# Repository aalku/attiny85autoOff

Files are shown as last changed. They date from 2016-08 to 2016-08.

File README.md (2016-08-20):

# attiny85autoOff
Circuit/Software that allow Attiny 85 to be powered on with a button and later power off itself.

With this circuit your microcontroller consume no power until a button is pressed. It is powered while the button is down but it can hold it's own power on once the button is released and later let itself go off when the program commands it.

All this only uses one I/O pin of the microcontroller so it really suits attiny85 that only have 5 of them.
Additionaly once the microcontroller is on it can read if the button is pressed or not. You can use it for power off or any other thing. So you can tell not even that pin is wasted. It must be an analog pin. This should work with any microcontroller capable of turning on a pullup resistor on an analog I/O pin and then set it as a low level output.

The basic circuit uses 5 resistors and two transistors. The example code uses a led (with it's associated resistor) to show power status and another to show if the button is pressed and signal when the power off is commanded by the program. All this is optional.

I used a similar design to make a thermometer that turned on with a button and turned off after 30s but that one used an additional pin to sense the button once powered on. That is not needed any more with this new design.

Please feel free to contribute however you want.

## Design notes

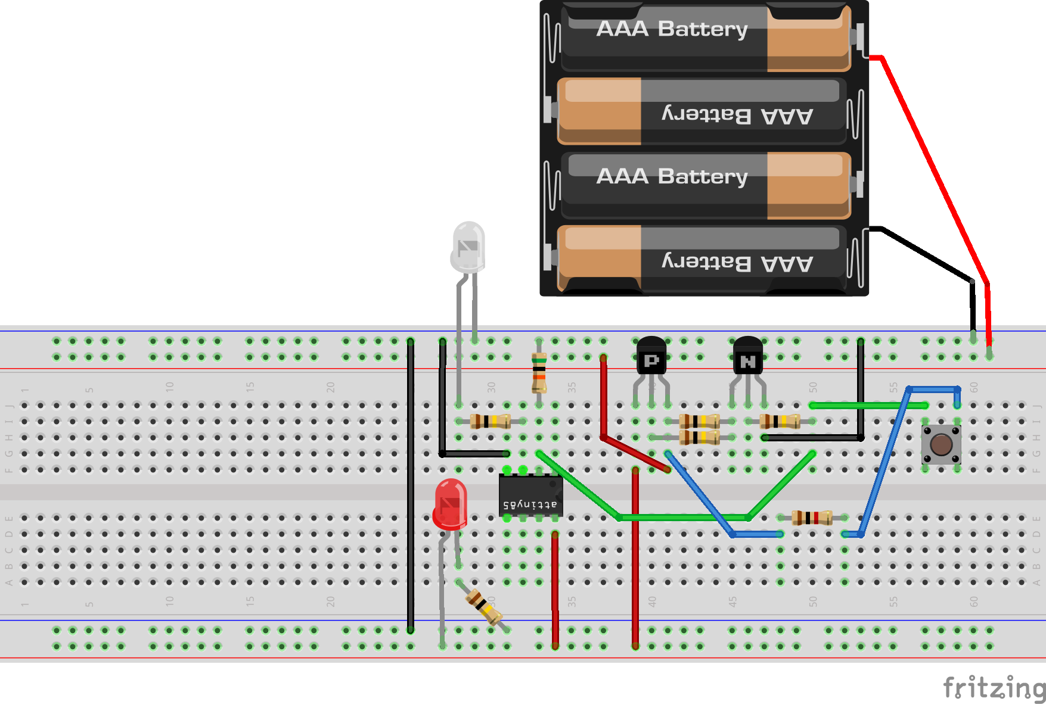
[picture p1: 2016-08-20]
attiny85AutoOff1Pin_bb.png

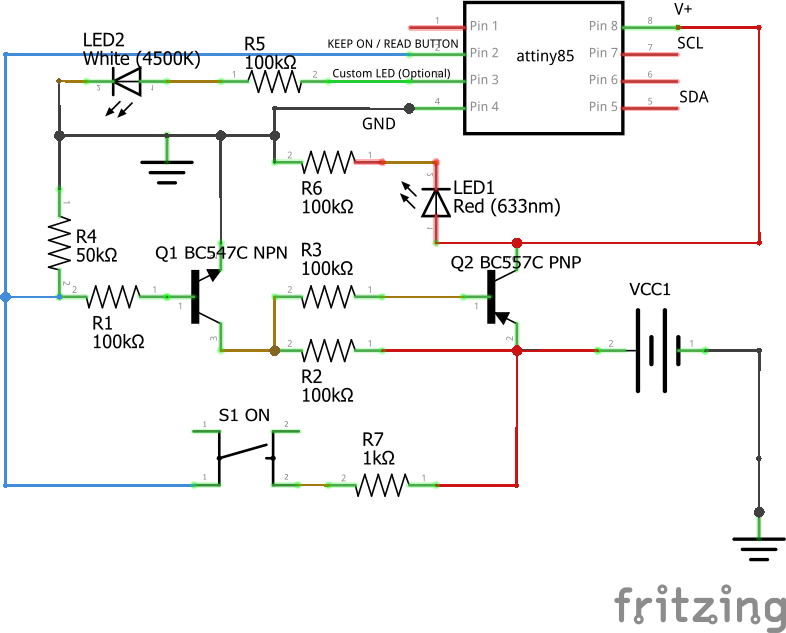
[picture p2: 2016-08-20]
attiny85AutoOff1Pin_schem.png

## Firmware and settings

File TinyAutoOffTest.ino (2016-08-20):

unsigned long t0;

int ledPin = 4;
int powerPin = A3;

void setup() {
  pinMode(ledPin, OUTPUT); // Read test LED
  digitalWrite(ledPin, LOW); // LED OFF
  pinMode(powerPin, INPUT); // Pin as input
  digitalWrite(powerPin, HIGH); // KEEP ON with internal pullup resistor
  t0 = millis(); // Boot time, always 0
}

void loop() {
  delay(5); // Or something
  if (millis() - t0 > 5000) { // Turn off after 5s
    // Blink
    digitalWrite(ledPin, HIGH);
    delay(100);
    digitalWrite(ledPin, LOW);
    delay(100);
    digitalWrite(ledPin, HIGH);
    delay(100);
    digitalWrite(ledPin, LOW);

    // Power off
    pinMode(powerPin, OUTPUT); // Full output, not only pull up/down resistor
    digitalWrite(powerPin, LOW); // Turn the whole thing off
    delay(500);

    // If still alive the button must be pressed, lets stop the power sink through the button to powerPin and restart
    pinMode(powerPin, INPUT); // Pin as input
    digitalWrite(powerPin, HIGH); //  ON with internal pullup resistor
    t0 = millis();
  }
  digitalWrite(ledPin, analogRead(powerPin) > 1024*2/3); // Turn on led if A3 is > 2/3 of VCC
}

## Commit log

2016-08-20 Arduino code
2016-08-20 Fritzing file so you can edit the designs.
    [attiny85AutoOff1Pin.fzz]
2016-08-20 Added leds and an extra resistor to...
    Extra resistor to reduce current drawn from battery sinked to attiny pin 2 when the button is pressed while the code decides to power off.
    Optional leds to signal power status and software actions.
    [attiny85AutoOff1Pin.fzz]
2016-08-20 Software power sink through button prevention
    Software power sink through button prevention and restart if the code decides to power off and the button is pressed
    [TinyAutoOffTest.ino]
